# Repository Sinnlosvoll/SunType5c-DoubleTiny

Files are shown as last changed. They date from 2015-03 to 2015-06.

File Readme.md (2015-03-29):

# What is this about? #
This project aims to connect a Sun Type 5c I found to a pc without any drivers and only with the help of 2 Attiny85s.

## Why don't I keep this to myself but publish it to github? ##
Because I am a generous person and don't want to keep this to myself. Also if someone finds one of those awesome keyboards, they should be able to use it.
And I want a central storage for all my stuff/documentation and file versioning. Mostly the last one. ^^

## Why 2 ICs and not 1? ##
Initially I planned to do all the polling and USB reporting on a single AT85; but that wouldn't work. 
The realtime components of emulating a USB device via software [(V-USB)](http://www.obdev.at/products/vusb/index-de.html) and the relatively low baud on the keyboard side of 1200 conflicted.
So two should resolve that hurdle by decoupling those two requirements while still allowing me to complete this project without expensive and larger flasher and boards.

## So what's the plan, chief? ##
Basically there is a master AT85, which handles USB communication and a buffer AT85 which handles communication with the keyboard and acts as a two-way buffer for events and commands.

# Now it's gonna get technical, be warned. #

### USB ###
The hardware-USB-implementation is heavily *cough* borrowed *cough* from [codeandlifes.com blog entry](http://codeandlife.com/2012/02/22/v-usb-with-attiny45-attiny85-without-a-crystal/).
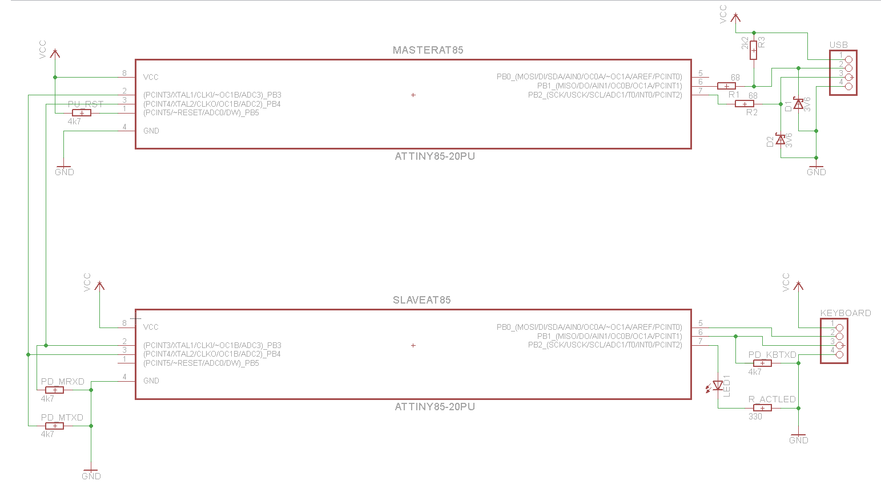
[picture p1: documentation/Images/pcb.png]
planned layout
The plan looks like this: 
Software is (as of right now) based on [another blog entry](http://codeandlife.com/2012/06/18/usb-hid-keyboard-with-v-usb/) and extended by myself.

### Keyboard interface ###
The Type 5c uses an async 1200 baud non-inverted signal with one bit to signal the start of a transfer and then following 8 bit. If the last bit is high, then this is the last bit in this message. Else the reciever should wait for more packets.
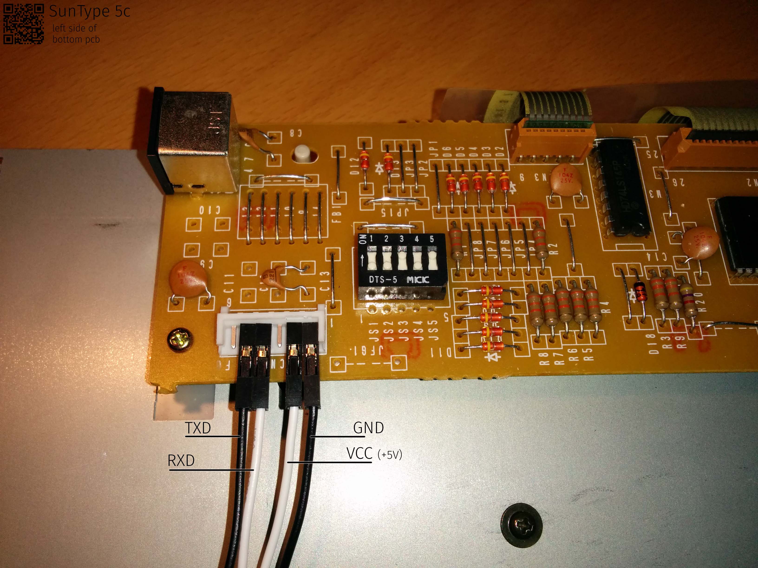
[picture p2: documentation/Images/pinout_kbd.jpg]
keyboard pins

That is my personal experience using a logic analyzer, so official documentation might differ, but that is really hard to prove with the lack of official documentation out there. I found a document describing general Sparc keyboard, altough I lost the sourcelink. You can find it it [documentation/Sparcs.pdf](documentation/Sparcs.pdf)

### Tiny-Tiny-interface ###
The two IC's are connected via 2 wired, both with a 4.7K pull-down to ground. The slave signals communication by rasing its flow-control-line high, so the master doesn't request any data. If the flwcntrl is low, then the master can send a 8-bit command to the slave, by raising it's txd for 70µ, then sending each bit for 70µs afterwards. The slave never initiates transfers.
If the command requires a respone such as ("what keys where pressed?") the master raises the flwcntrl line for each bit and the slave shall send one bit as long as the flwcntrl line is kept high. The master then pulles it low for 10µs and requests the next bit. *This is slow but probably needed to keep the master idling enough for v-usb to work*.

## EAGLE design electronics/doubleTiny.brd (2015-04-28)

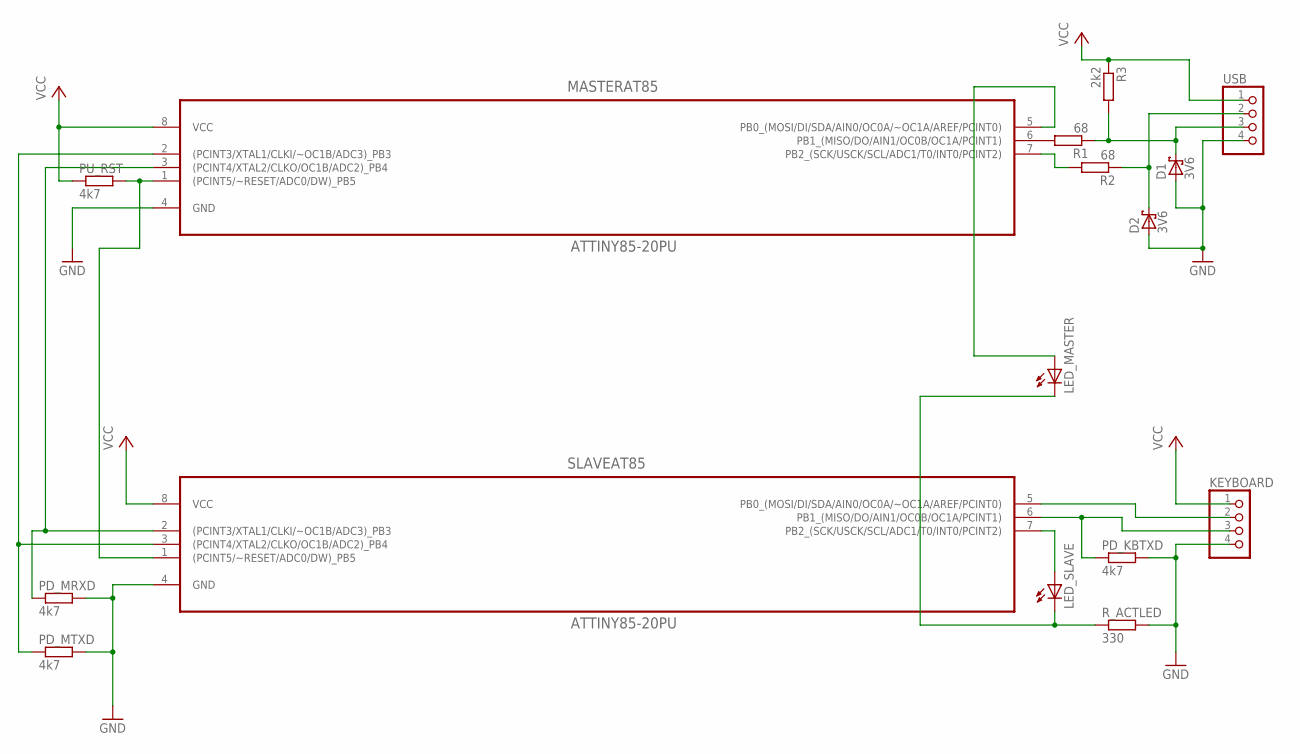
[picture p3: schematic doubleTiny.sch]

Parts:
D1, D2: 3V6; C4111-15
KEYBOARD: PINHD-1X4; 1X04
LED_MASTER: LED3MM
LED_SLAVE: LED5MM
MASTERAT85: ATTINY85-20PU; DIP254P762X533-8
PD_KBTXD: 4k7; 0309/12
PD_MRXD: 4k7; 0309/12
PD_MTXD: 4k7; 0309/12
PU_RST: 4k7; 0309/12
R1, R2: 68; 0309/12
R3: 2k2; 0309/12
R_ACTLED: 330; 0309/12
SLAVEAT85: ATTINY85-20PU; DIP254P762X533-8
USB: PINHD-1X4; 1X04

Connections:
GND: D1.A, D2.A, KEYBOARD.4, MASTERAT85.4 (GND), PD_KBTXD.2, PD_MRXD.2, PD_MTXD.2, R_ACTLED.2, SLAVEAT85.4 (GND), USB.4
unnamed: MASTERAT85.7 (PB2_(SCK/USCK/SCL/ADC1/T0/INT0/PCINT2)), R2.2
unnamed: MASTERAT85.6 (PB1_(MISO/DO/AIN1/OC0B/OC1A/PCINT1)), R1.2
unnamed: D1.C, R1.1, R3.2, USB.3
unnamed: D2.C, R2.1, USB.2
unnamed: KEYBOARD.2, SLAVEAT85.5 (PB0_(MOSI/DI/SDA/AIN0/OC0A/~OC1A/AREF/P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)
unnamed: MASTERAT85.3 ((PCINT4/XTAL2/CLKO/OC1B/ADC2)_PB4), PD_MRXD.1, SLAVEAT85.2 ((PCINT3/XTAL1/CLKI/~OC1B/ADC3)_PB3)
unnamed: MASTERAT85.2 ((PCINT3/XTAL1/CLKI/~OC1B/ADC3)_PB3), PD_MTXD.1, SLAVEAT85.3 ((PCINT4/XTAL2/CLKO/OC1B/ADC2)_PB4)
unnamed: KEYBOARD.3, PD_KBTXD.1, SLAVEAT85.6 (PB1_(MISO/DO/AIN1/OC0B/OC1A/PCINT1))
unnamed: MASTERAT85.1 ((PCINT5/~RESET/ADC0/DW)_PB5), PU_RST.2, SLAVEAT85.1 ((PCINT5/~RESET/ADC0/DW)_PB5)
unnamed: LED_MASTER.A, MASTERAT85.5 (PB0_(MOSI/DI/SDA/AIN0/OC0A/~OC1A/AREF/P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)
unnamed: LED_SLAVE.A, SLAVEAT85.7 (PB2_(SCK/USCK/SCL/ADC1/T0/INT0/PCINT2))
unnamed: LED_MASTER.K (C), LED_SLAVE.K (C), R_ACTLED.1
VCC: KEYBOARD.1, MASTERAT85.8 (VCC), PU_RST.1, R3.1, SLAVEAT85.8 (VCC), USB.1

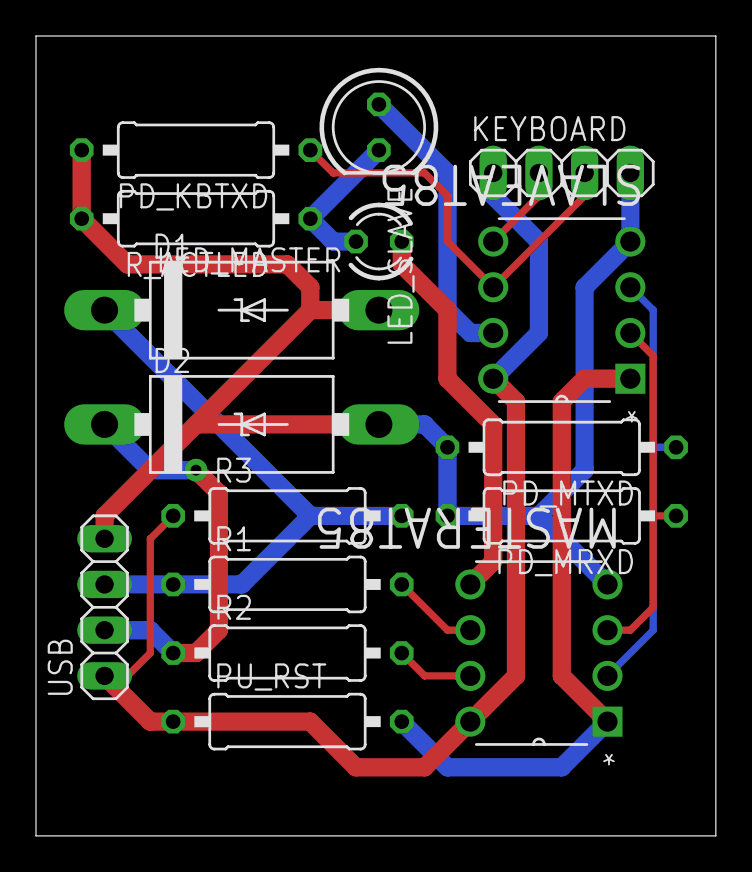
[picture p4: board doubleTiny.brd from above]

Board: 2 copper layers, 37.8 x 44.4 mm, 16 parts (0 on the bottom side), 14 nets.

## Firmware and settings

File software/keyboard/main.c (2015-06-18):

/**
 * Original-Project: AVR ATtiny USB Tutorial at http://codeandlife.com/
 * Original-Author: Joonas Pihlajamaa, joonas.pihlajamaa@iki.fi
 * Base on V-USB example code by Christian Starkjohann
 * Copyright: (c) 2008 by OBJECTIVE DEVELOPMENT Software GmbH
 * License: GNU GPL v3 (see License.txt)
 */
#include <avr/io.h>
#include <avr/interrupt.h>
#include <avr/wdt.h>
#include <avr/eeprom.h>
#include <util/delay.h>
#include <math.h>


typedef struct {
	uint8_t firstByte;
	uint8_t secondByte;
	uint8_t thirdByte;
} byteBuffer_t;

byteBuffer_t byteBuffer;
signed char keys_pressed = 0;


unsigned char i = 0;
unsigned counter = 0;
unsigned char globalStorage = 0;
//  globalStorage & 0x08 show currently reading state
//  globalStorage & 0x01 shows last pin Read
//  globalStorage & 0x02 indicates whether lastPinReadIsSet
//  globalStorage & 0x10 is set when rs232Counters have to be reset
unsigned char currentBitReading = 0;
unsigned char currentBitWriting = 0;
unsigned char keyboard_keys_down[6];
unsigned char command = 0;
uint64_t USBSendBuffer = 0;
unsigned char haveToSendBackCounter = 0;
unsigned char bitsReadFromUSB = 0;
uint8_t clkPinState = 0; // kinda broad assumption but delays everywhere and the clock shouldn't start 
 // right away since usb has to be initialised and such


#define RXDPIN PB4
#define CLKPIN PB3
#define LEDPIN PB0
#define KRXPIN PB1
#define KTXPIN PB2

#define ledON() (PORTB |= 1 << LEDPIN)
#define ledOFF() (PORTB &= ~(1 << LEDPIN))
#define setRecieve() (DDRB = 0 << RXDPIN)
#define setSend() (DDRB = 1 << RXDPIN)


void key_down(uint8_t down_key) {
	/* we only add a key to our pressed list, when we have less than 6 already pressed.
	** additional keys will be ignored  */
	if (keys_pressed < 6)
	{
		keyboard_keys_down[keys_pressed] = down_key;
		keys_pressed++;
	}
}

void key_up(uint8_t up_key) {
	uint8_t n;
	for (i = 0; i < 6; i++)
	{
		if (keyboard_keys_down[i] == up_key)
		{
			for (n = i; n <= 4; n++ )
			{
				keyboard_keys_down[n] = keyboard_keys_down[n + 1];
			}
			keyboard_keys_down[5] = 0;
			keys_pressed--;
			break;
		}
	}
}

unsigned char mapReadByte(toSwitch) {
	switch(toSwitch) {
		case 0x1C: return 0x56; /* keypad -  */
		default: return 0x04; /* keyboard a  */
	}
}

void resetRs232Counters() {

	byteBuffer.firstByte  = 0;
	byteBuffer.secondByte = 0;
	byteBuffer.thirdByte  = 0;
	counter               = 0;
	globalStorage         &= ~(0x10);
	currentBitReading     = 0;
	currentBitWriting     = 0;
	TIMSK                 &= ~(1 << TOIE0); 
	// disable timer div 8 interrupt, since we only need them when the keyboard sends stuff

}

void reportKeysDown() {

	uint8_t n;
	setSend();
	haveToSendBackCounter = 4 + (keys_pressed * 8);
	bitsReadFromUSB = 0;
	USBSendBuffer = 0;
	for (i = 3; i >= 0; i--)
	{
		// add the number of keys in the report to be sent out first in 4 bits
		USBSendBuffer |= ((((uint64_t)keys_pressed >> i) & 0x01) << 63);
		USBSendBuffer = (USBSendBuffer >> 1);
	}
	for (i = 0; i < keys_pressed; i++)
	{
		for (n = 0; n < 8; n++)
		{
			// TODO: check if this works
			USBSendBuffer |=  ((((uint64_t)keyboard_keys_down[i] >> n) & 0x01) << 63);
			USBSendBuffer = (USBSendBuffer >> 1);
		}
		
	}
	USBSendBuffer = (USBSendBuffer >> ((63 - 1) - haveToSendBackCounter));
	// probably this amount ( 63-1 due to the last shift in the n-loop), TODO: test this assumption

}

void turnOnCapsLock() {
	// for testing only
	ledON();
}

void turnOffCapsLock() {
	ledOFF();
}

void checkCommand() {
	switch (command) {
		case 0b00001111: reportKeysDown(); break;
		case 0b00001001: turnOnCapsLock(); break;
		case 0b00001101: turnOffCapsLock(); break;
		default: ledON(); break; // maybe blink led somehow here
	}
}

int main() {
	
	// Master-side pin inits
	DDRB |= 0 << RXDPIN; // input
	DDRB |= 0 << CLKPIN; // input
	PORTB |= 0 << RXDPIN; // deactivate pull-up resistor
	PORTB |= 0 << CLKPIN; // deactivate pull-up resistor

	// Keyboard-side pin inits
	DDRB |= 0 << KRXPIN; // input 
	DDRB |= 1 << KTXPIN; // output
	PORTB |= 0 << KRXPIN; // deactivate pull-up resistor
	PORTB |= 0 << KTXPIN; // set low by default, so no weird stuff happens

	// LED
	DDRB |= 1 << LEDPIN;
	PORTB |= 0 << LEDPIN;
	
	TCCR0B |= (1 << CS01); // timer 0 at clk/8 will generate randomness and also serves as a 
	GIMSK |= (1 << PCIE); // allow pin change interupts for PCINT[0-5]
	PCMSK = (1 << PCINT1); // enable pin change interrupt for the KRXPIN
	PCMSK |= (1 << PCINT3); // enable pin change interrupt for the CLKPIN
	

	for(i=0; i<sizeof(keyboard_keys_down); i++) // clear report initially
		keyboard_keys_down[i] = 0;
	
	wdt_enable(WDTO_1S); // enable 1s watchdog timer
	sei(); // Enable interrupts after re-enumeration
	
	while(1) {
		
		wdt_reset(); // keep the watchdog happy
		if ((bitsReadFromUSB & 0x04))
		{
			// 4 bits read, therefore command is done
			checkCommand();
		}

		// TIMSK &= (0 << TOIE0);

		if ((globalStorage & 0x08)) // currently reading
		{
			do
			{
				_delay_us(200);
				wdt_reset();
			} while ((globalStorage & 0x08));
		}

		// TIMSK |= (1 << TOIE0); /* enable timer overflow interupts */
	}
	
	return 0;
}

void charDetected(uint8_t detected) {

	if(currentBitReading == 0 || currentBitReading == 9 || currentBitReading == 18) {
		if ((detected & 0x01))
		{
			/* we should only allow valid frame delimters (1)s to advance our counting */
			currentBitReading++;
			return;       
		} else {
			/* in here we could think of some error handling if we wanted*/
			return;
		}
	}

	if (currentBitWriting >> 4)
	{
		byteBuffer.thirdByte  = (byteBuffer.thirdByte  << 1);
		if ((detected & 0x01))
			byteBuffer.thirdByte  += 0x01;

	} else if (currentBitWriting >> 3) 
	{
		byteBuffer.secondByte = (byteBuffer.secondByte << 1); 
		if ((detected & 0x01))
			byteBuffer.secondByte += 0x01;

	} else {
		byteBuffer.firstByte  = (byteBuffer.firstByte  << 1);
		if ((detected & 0x01))
			byteBuffer.firstByte  += 0x01;
	}

	if (currentBitWriting == 7 && (detected & 0x01))
	{
		ledON();
		key_down( mapReadByte(byteBuffer.firstByte & 0xFE) );
		globalStorage |= 0x10;
		ledOFF();
	}

	if (currentBitWriting == 15 && (detected & 0x01))
	{
		ledON();
		key_up( mapReadByte(byteBuffer.firstByte & 0xFE) );
		globalStorage |= 0x10;
		ledOFF();
	}

	currentBitReading++;
	currentBitWriting++;
	if((globalStorage & 0x10))
		resetRs232Counters();
	
	
}










void pinChange3() {
	// usbT side

	// interupt handler for a clk signal in PB3 which either means that we recieve a bit or are asked to send one
	// so it is: check if send(1) or recieve(2); (1): push next bit to RXDPIN; (2): read RXDPIN and add to 
	// interpreterbuffer 
	// 
	if (PINB << CLKPIN)
	{
		// only when changed to high

		if (haveToSendBackCounter != 0)
		{
			// send the next byte out of RXDPIN
			if (USBSendBuffer & 0x01)
			{
				PORTB |= (1 << RXDPIN);
			} else {
				PORTB &= ~(1 << RXDPIN);
			}
			USBSendBuffer = (USBSendBuffer >> 1);
			haveToSendBackCounter--;
			if (haveToSendBackCounter == 0)
			{
				// set Pin back as input so we can recieve new messages
				// as we are finished woth sending all bits
				setRecieve();
			}

		} else {
			// when there is a clock signal and we have nothing left in our queue
			// we'll hopefully recieve a new command
			command = (command << 1);
			command |= (PINB << RXDPIN);
			bitsReadFromUSB++;
		}
	}
}

void pinChange1() {
	// Keyboard site
	// each 
	
	if ((globalStorage  & 0x02)) // lastPinRead is set, so to save time reading the pin (again(interrupt from change)) we just toggle the 'current' read value
	{
		globalStorage ^= 0x01; // flip last bit to current value

	} else {
		globalStorage &= ~(0x01); // clear last bit
		globalStorage |= (PINB & (1 << RXDPIN)); // set last read
		globalStorage |= 0x02; //from now on don't read again but toggle and read from register
	}
	if (globalStorage & 0x01) // last bit read is 1
	{
		// this is only done once per byte sent by the keyboard
		globalStorage |= 0x08; // show currently reading state 
		TIMSK |= (1 << TOIE0);  //enable timer overflow interupts 

	} else {
		// check if byte is done
		// or not, since the interpreter does that already
	}


}


ISR(PCINT0_vect) {

	if ((PINB & (1 << CLKPIN)) != clkPinState) // clock changed
	{
		if (clkPinState)
		{
			ledON();
		} else {
			ledOFF();
		}
		pinChange3();
		clkPinState ^= 0x01; // flip last state to current one

	} else {
		pinChange1(); 
		// we only have 2 possible interrupts so this should work fine
	}
	
	

}

ISR(TIMER0_OVF_vect) 
{
	counter++;
	if ((globalStorage & 0x01) ^ ((globalStorage & 0x04) >> 2) ) // current read is different from last
	{
		counter = floor(counter / 6);
		for (i = 0; i < counter; i++)
		{
			charDetected(~(globalStorage & 0x01));
			// the counter increments about 6 times per bit sent by the kb
			// so when it changes there were floor(counter/6) bits of the ~(now) state
		}
	}
}

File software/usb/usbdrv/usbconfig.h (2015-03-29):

/* Name: usbconfig.h
 * Project: V-USB, virtual USB port for Atmel's(r) AVR(r) microcontrollers
 * Author: Christian Starkjohann
 * Creation Date: 2005-04-01
 * Tabsize: 4
 * Copyright: (c) 2005 by OBJECTIVE DEVELOPMENT Software GmbH
 * License: GNU GPL v2 (see License.txt), GNU GPL v3 or proprietary (CommercialLicense.txt)
 * This Revision: $Id$
 */

#ifndef __usbconfig_h_included__
#define __usbconfig_h_included__

/*
General Description:
This file is an example configuration (with inline documentation) for the USB
driver. It configures V-USB for USB D+ connected to Port D bit 2 (which is
also hardware interrupt 0 on many devices) and USB D- to Port D bit 4. You may
wire the lines to any other port, as long as D+ is also wired to INT0 (or any
other hardware interrupt, as long as it is the highest level interrupt, see
section at the end of this file).
*/

/* ---------------------------- Hardware Config ---------------------------- */

#define USB_CFG_IOPORTNAME      B
/* This is the port where the USB bus is connected. When you configure it to
 * "B", the registers PORTB, PINB and DDRB will be used.
 */
#define USB_CFG_DMINUS_BIT      1
/* This is the bit number in USB_CFG_IOPORT where the USB D- line is connected.
 * This may be any bit in the port.
 */
#define USB_CFG_DPLUS_BIT       2
/* This is the bit number in USB_CFG_IOPORT where the USB D+ line is connected.
 * This may be any bit in the port. Please note that D+ must also be connected
 * to interrupt pin INT0! [You can also use other interrupts, see section
 * "Optional MCU Description" below, or you can connect D- to the interrupt, as
 * it is required if you use the USB_COUNT_SOF feature. If you use D- for the
 * interrupt, the USB interrupt will also be triggered at Start-Of-Frame
 * markers every millisecond.]
 */
#define USB_CFG_CLOCK_KHZ       (F_CPU/1000)
/* Clock rate of the AVR in kHz. Legal values are 12000, 12800, 15000, 16000,
 * 16500, 18000 and 20000. The 12.8 MHz and 16.5 MHz versions of the code
 * require no crystal, they tolerate +/- 1% deviation from the nominal
 * frequency. All other rates require a precision of 2000 ppm and thus a
 * crystal!
 * Since F_CPU should be defined to your actual clock rate anyway, you should
 * not need to modify this setting.
 */
#define USB_CFG_CHECK_CRC       0
/* Define this to 1 if you want that the driver checks integrity of incoming
 * data packets (CRC checks). CRC checks cost quite a bit of code size and are
 * currently only available for 18 MHz crystal clock. You must choose
 * USB_CFG_CLOCK_KHZ = 18000 if you enable this option.
 */

/* ----------------------- Optional Hardware Config ------------------------ */

/* #define USB_CFG_PULLUP_IOPORTNAME   D */
/* If you connect the 1.5k pullup resistor from D- to a port pin instead of
 * V+, you can connect and disconnect the device from firmware by calling
 * the macros usbDeviceConnect() and usbDeviceDisconnect() (see usbdrv.h).
 * This constant defines the port on which the pullup resistor is connected.
 */
/* #define USB_CFG_PULLUP_BIT          4 */
/* This constant defines the bit number in USB_CFG_PULLUP_IOPORT (defined
 * above) where the 1.5k pullup resistor is connected. See description
 * above for details.
 */

/* --------------------------- Functional Range ---------------------------- */
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

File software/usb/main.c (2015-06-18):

/**
 * Project: AVR ATtiny USB Tutorial at http://codeandlife.com/
 * Author: Joonas Pihlajamaa, joonas.pihlajamaa@iki.fi
 * Base on V-USB example code by Christian Starkjohann
 * Copyright: (c) 2008 by OBJECTIVE DEVELOPMENT Software GmbH
 * License: GNU GPL v3 (see License.txt)
 */
#include <avr/io.h>
#include <avr/interrupt.h>
#include <avr/wdt.h>
#include <avr/eeprom.h>
#include <util/delay.h>
#include <math.h>

#include "usbdrv.h"

// ************************
// *** USB HID ROUTINES ***
// ************************

// From Frank Zhao's USB Business Card project
// http://www.frank-zhao.com/cache/usbbusinesscard_details.php
PROGMEM const char usbHidReportDescriptor[USB_CFG_HID_REPORT_DESCRIPTOR_LENGTH] = {
	0x05, 0x01,                    // USAGE_PAGE (Generic Desktop)
	0x09, 0x06,                    // USAGE (Keyboard)
	0xa1, 0x01,                    // COLLECTION (Application)
	0x75, 0x01,                    //   REPORT_SIZE (1)
	0x95, 0x08,                    //   REPORT_COUNT (8)
	0x05, 0x07,                    //   USAGE_PAGE (Keyboard)(Key Codes)
	0x19, 0xe0,                    //   USAGE_MINIMUM (Keyboard LeftControl)(224)
	0x29, 0xe7,                    //   USAGE_MAXIMUM (Keyboard Right GUI)(231)
	0x15, 0x00,                    //   LOGICAL_MINIMUM (0)
	0x25, 0x01,                    //   LOGICAL_MAXIMUM (1)
	0x81, 0x02,                    //   INPUT (Data,Var,Abs) ; Modifier byte
	0x95, 0x01,                    //   REPORT_COUNT (1)
	0x75, 0x08,                    //   REPORT_SIZE (8)
	0x81, 0x03,                    //   INPUT (Cnst,Var,Abs) ; Reserved byte
	0x95, 0x05,                    //   REPORT_COUNT (5)
	0x75, 0x01,                    //   REPORT_SIZE (1)
	0x05, 0x08,                    //   USAGE_PAGE (LEDs)
	0x19, 0x01,                    //   USAGE_MINIMUM (Num Lock)
	0x29, 0x05,                    //   USAGE_MAXIMUM (Kana)
	0x91, 0x02,                    //   OUTPUT (Data,Var,Abs) ; LED report
	0x95, 0x01,                    //   REPORT_COUNT (1)
	0x75, 0x03,                    //   REPORT_SIZE (3)
	0x91, 0x03,                    //   OUTPUT (Cnst,Var,Abs) ; LED report padding
	0x95, 0x06,                    //   REPORT_COUNT (6)
	0x75, 0x08,                    //   REPORT_SIZE (8)
	0x15, 0x00,                    //   LOGICAL_MINIMUM (0)
	0x25, 0x65,                    //   LOGICAL_MAXIMUM (101)
	0x05, 0x07,                    //   USAGE_PAGE (Keyboard)(Key Codes)
	0x19, 0x00,                    //   USAGE_MINIMUM (Reserved (no event indicated))(0)
	0x29, 0x65,                    //   USAGE_MAXIMUM (Keyboard Application)(101)
	0x81, 0x00,                    //   INPUT (Data,Ary,Abs)
	0xc0                           // END_COLLECTION
};

/*USB defs*/
typedef struct {
	uint8_t modifier;
	uint8_t reserved;
	uint8_t keycode[6];
} keyboard_report_t;

typedef struct {
	uint8_t numberOfOpenRequests;
	uint8_t lengths[6];
	uint8_t commands[6];
} async_queue_t;

static keyboard_report_t keyboard_report; // sent to PC
async_queue_t async_queue;
volatile static uchar LED_state = 0xff; // received from PC
static uchar idleRate; // repeat rate for keyboards

int8_t keys_pressed = 0;
uint8_t i = 0;
uint8_t keyHash = 0;

usbMsgLen_t usbFunctionSetup(uchar data[8]) {
	usbRequest_t *rq = (void *)data;

	if((rq->bmRequestType & USBRQ_TYPE_MASK) == USBRQ_TYPE_CLASS) {
		switch(rq->bRequest) {
		case USBRQ_HID_GET_REPORT: // send "no keys pressed" if asked here
			// wValue: ReportType (highbyte), ReportID (lowbyte)
			usbMsgPtr = (void *)&keyboard_report; // we only have this one
			keyboard_report.modifier = 0;
			keyboard_report.keycode[0] = 0;
			return sizeof(keyboard_report);
		case USBRQ_HID_SET_REPORT: // if wLength == 1, should be LED state
			return (rq->wLength.word == 1) ? USB_NO_MSG : 0;
		case USBRQ_HID_GET_IDLE: // send idle rate to PC as required by spec
			usbMsgPtr = &idleRate;
			return 1;
		case USBRQ_HID_SET_IDLE: // save idle rate as required by spec
			idleRate = rq->wValue.bytes[1];
			return 0;
		}
	}
	
	return 0; // by default don't return any data
}

#define CLKPIN PB3
#define DATPIN PB4
#define LEDPIN PB0
 // usb pins are defined in usbconfig.h
#define ledON() (PORTB |= 1 << LEDPIN)
#define ledOFF() (PORTB &= ~(1 << LEDPIN))

#define NUM_LOCK 1
#define CAPS_LOCK 2
#define SCROLL_LOCK 4



// not needed as the report is built by key_{up, down}
void buildReport(uchar send_key) {
	keyboard_report.modifier = 0;
	
	if(send_key >= 'a' && send_key <= 'z')
		keyboard_report.keycode[0] = 4+(send_key-'a');
	else
		keyboard_report.keycode[0] = 0;
}

uint8_t getBitsFromKeyboard(uint8_t length) {
	uint8_t recieved = 0;
	DDRB &= ~(1 << DATPIN); // change data pin over to inputh
	_delay_us(50);

	for (i = 0; i < length; i++	)
	{
		PORTB |= (1 << CLKPIN); // clock high, request bit
		// possible delay here, needs testing if needed
		_delay_us(50); // ah why not
		recieved |= ((PINB &  ( 1<< DATPIN)) >> (DATPIN -1)); // TODO: is this right?
		recieved = (recieved << 1); // reading MSB first
		PORTB &= ~(1 << CLKPIN); // set clock low
		_delay_us(50); // not set in stone
	}

	DDRB |= 1 << DATPIN; // change back to output to keep it consistent
	return recieved;
}

void sendBitsToKeyboard(uint8_t toSend, uint8_t length) {

	for (i = 0; i < length; i++	)
	{
		if (((toSend >> (length - i - 1)) & 0x01))
		{
			PORTB |= (1 << DATPIN); // send from left to right in msb-left notation
		} else {
			PORTB &= ~(1 << DATPIN); // since |= won't pull low
		}
		_delay_us(10);
		PORTB |= (1 << CLKPIN); // clock high
		// possible delay here, needs testing if needed
		_delay_us(50); // that would leave 825 cycles for the kbT to work
		PORTB &= ~(1 << CLKPIN); // set clock low
		_delay_us(50); // courtesy waiting
	}
	PORTB &= ~(1 << DATPIN);
}

usbMsgLen_t usbFunctionWrite(uint8_t * data, uchar len) {
	//ledON();
	if (data[0] == LED_state)
		return 1;
	else
		LED_state = data[0];
	
	// LED state changed
	if(LED_state & CAPS_LOCK) {

		PORTB |= 1 << LEDPIN; // LED on
		async_queue.commands[async_queue.numberOfOpenRequests] = 0b00001001;
		async_queue.lengths[async_queue.numberOfOpenRequests] = 4;
		async_queue.numberOfOpenRequests++;
	}
	else {
		PORTB &= ~(1 << LEDPIN); // LED off
		async_queue.commands[async_queue.numberOfOpenRequests] = 0b00001101;
		async_queue.lengths[async_queue.numberOfOpenRequests] = 4;
		async_queue.numberOfOpenRequests++;
	}
	
	return 1; // Data read, not expecting more
}

uint8_t updateKeysPressed() {

	uint8_t currentHash = 0;
	sendBitsToKeyboard(0b00001111, 4); // request keys pressed
	keys_pressed = getBitsFromKeyboard(4);
	return 0;
	for (i = 0; i < keys_pressed; i++)
	{
		keyboard_report.keycode[i] = getBitsFromKeyboard(8);
	}
	for (i = 0; i < 6; i++)
	{
		currentHash += keyboard_report.keycode[i];
		// this overflows and i know it
	}
	return currentHash;
}
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

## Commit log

2015-03-29 created readme and added files
    Created initial markdown explaining my goals and added pcb, schematics
    and some documentation from sparc i found somewhere
    [doubleTiny.sch]
2015-03-29 added pcb image
2015-03-29 added files from first try
    The license, in this case GPL3, only applies to files in /software, not
    documentation. The pdfs still belong to their rightful owners or
    rightholders. Not me
2015-04-27 updatet schematics and used usbT for capsLock
    [doubleTiny.sch]
2015-04-28 created first board layout and added led to master. Swapped usb pins and conglomerated resets
    [doubleTiny.brd, doubleTiny.sch]
2015-06-11 fixed readingdisplay in main loop kb-tiny and cleanup
    [main.c]
2015-06-15 pin fixes in kbT; pin-states and recieve function in usbT
    [main.c]
2015-06-16 cleanup of usbT and interrupts only when something changed
2015-06-16 minor fixes to allow compiling
    [main.c]
2015-06-16 changed kbT response to rise from falling and rise, disabled useless timers and documented some parts
2015-06-17 fixed writing zeroes, changed timing for kbT-usbT communication
    [main.c]
2015-06-18 changed kbT interrupt behaviour but it's not working yet. Adjusted timings and added asynchronous sending of messages from usbT to kbT
    [main.c]
